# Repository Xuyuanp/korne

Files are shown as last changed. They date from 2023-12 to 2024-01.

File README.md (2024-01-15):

# Korne

| left | right |
| --- | --- |
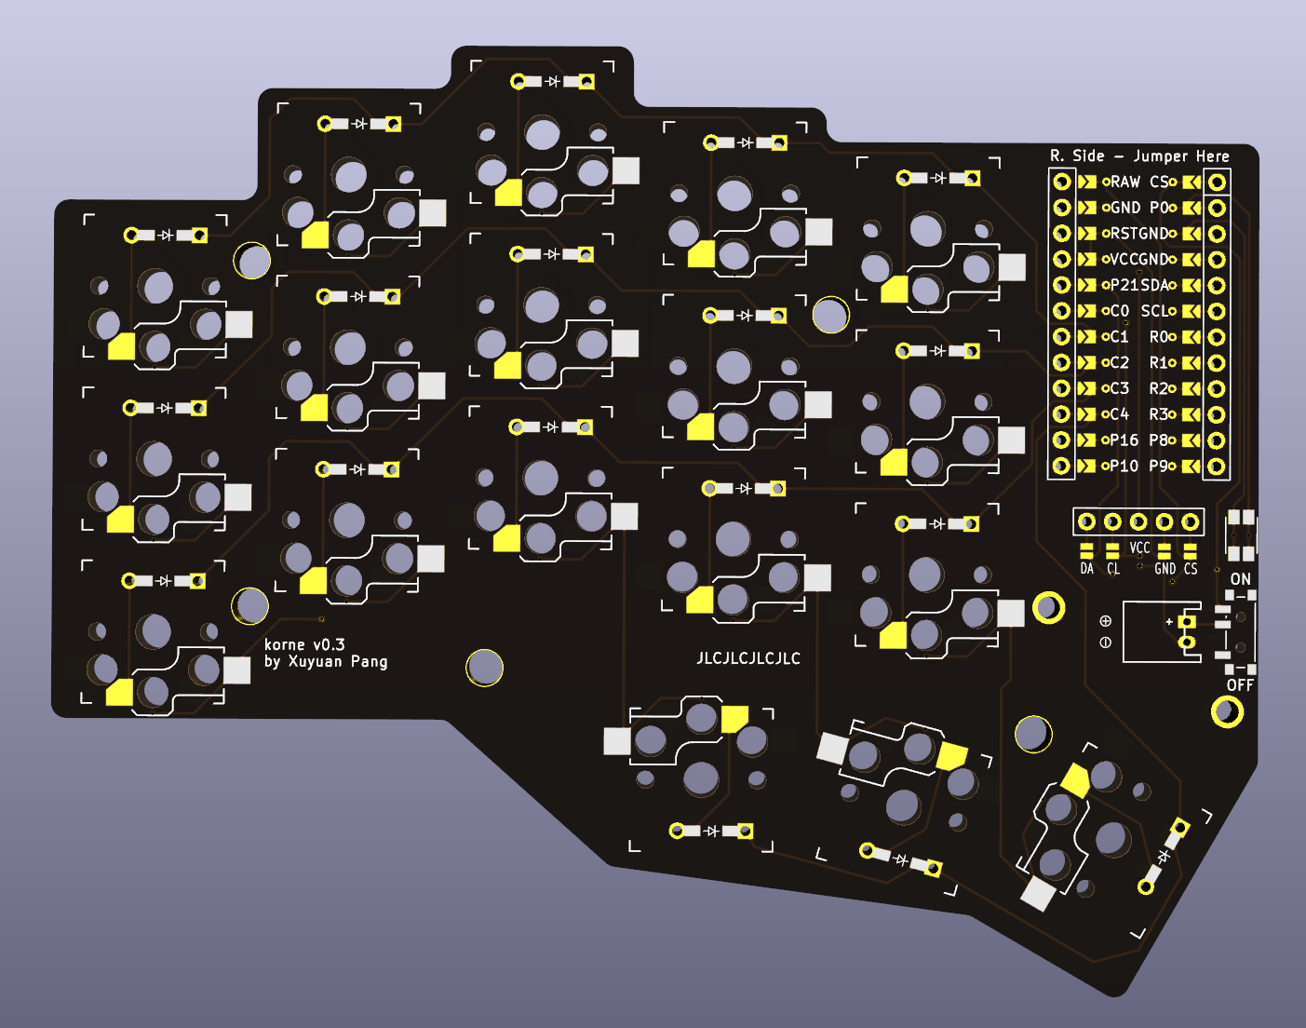
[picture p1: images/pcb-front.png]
front
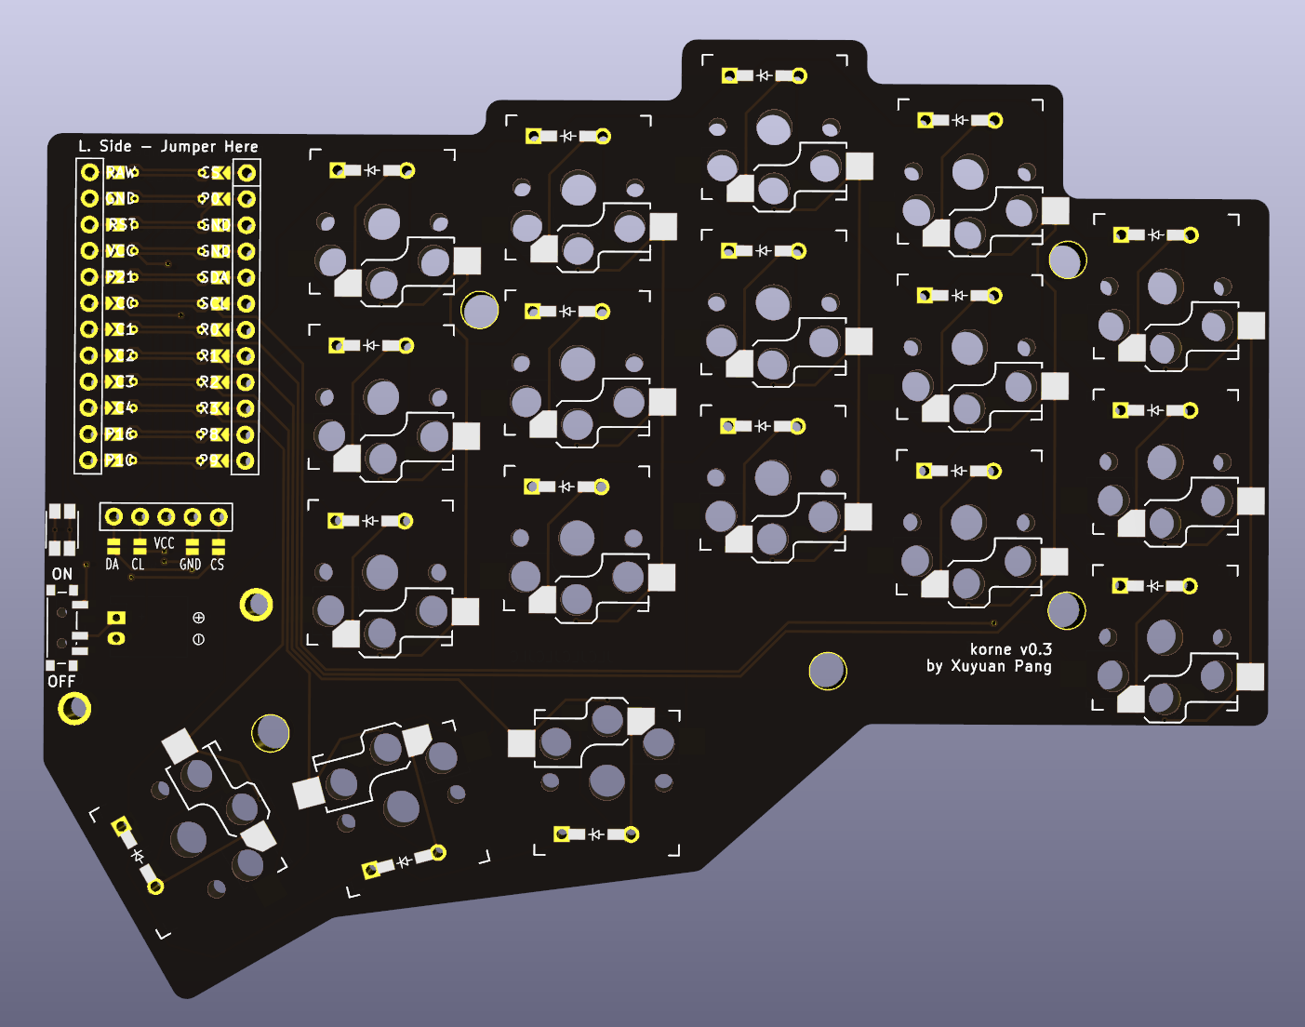
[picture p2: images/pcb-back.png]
back
|  |  |

## Features

- Declarative layout configuration (powered by ergogen)
- Reversible PCB design
- Nice!View support (not tested yet)
- Wireless only
- 3D printed magnetic cases
- Compatible with ZMK firmware of Corne
- The staggered layout fits my hands perfectly

## Credits

- [Ergogen](https://github.com/ergogen/ergogen)
- [ErgoPad](https://pashutk.com/ergopad/)
- [Flatfoot Fox's awesome blog](https://flatfootfox.com/ergogen-introduction/)
- [samoklava](https://github.com/soundmonster/samoklava)
- [infused-kim's footprints
](https://github.com/infused-kim/kb_ergogen_fp)

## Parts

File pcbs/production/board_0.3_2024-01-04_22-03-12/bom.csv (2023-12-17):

Designator | Footprint | Quantity | Value | LCSC Part #
H1, H2, H3, H4, H5, H6, H7 | mounting_hole | 7
JST1 | JST_PH_S2B-PH-K_02x2.00mm_Angled | 1
SW1 | sw_reset_side | 1
SW2 | power_switch | 1

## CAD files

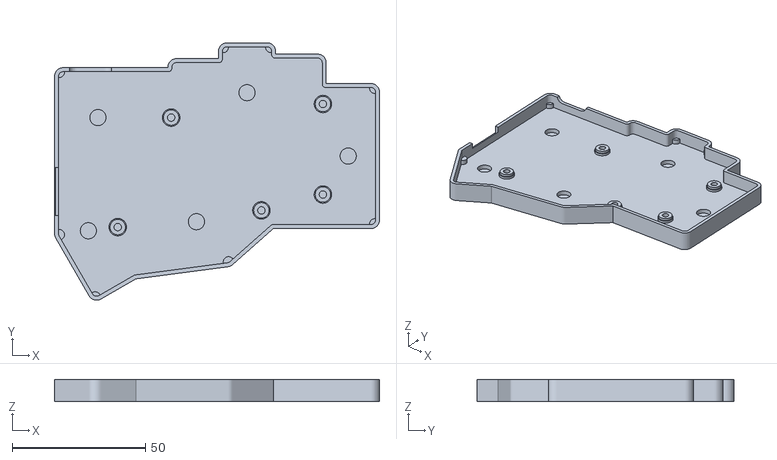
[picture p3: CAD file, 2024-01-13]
cases/bottom-mirrord.stl
122.1 x 96.7 x 8.30

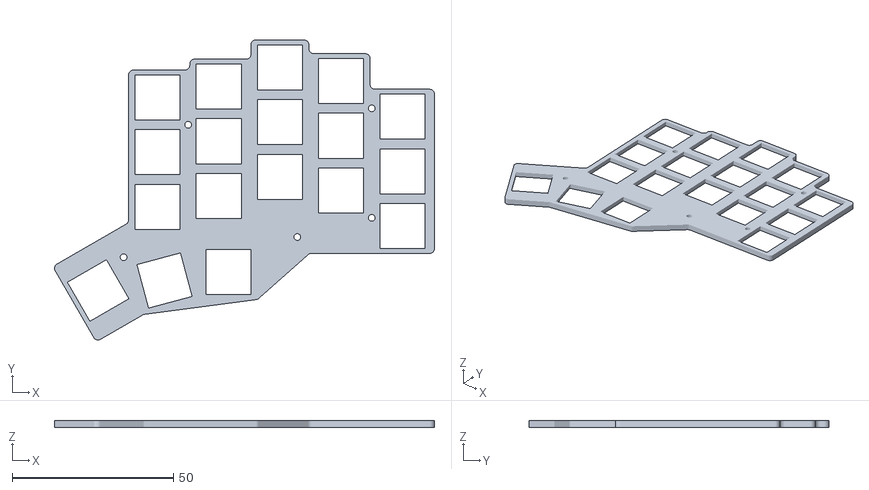
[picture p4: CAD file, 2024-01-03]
cases/top-mirrord.stl
118.0 x 93.2 x 2.20

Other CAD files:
cases/bottom.stl
cases/top.stl

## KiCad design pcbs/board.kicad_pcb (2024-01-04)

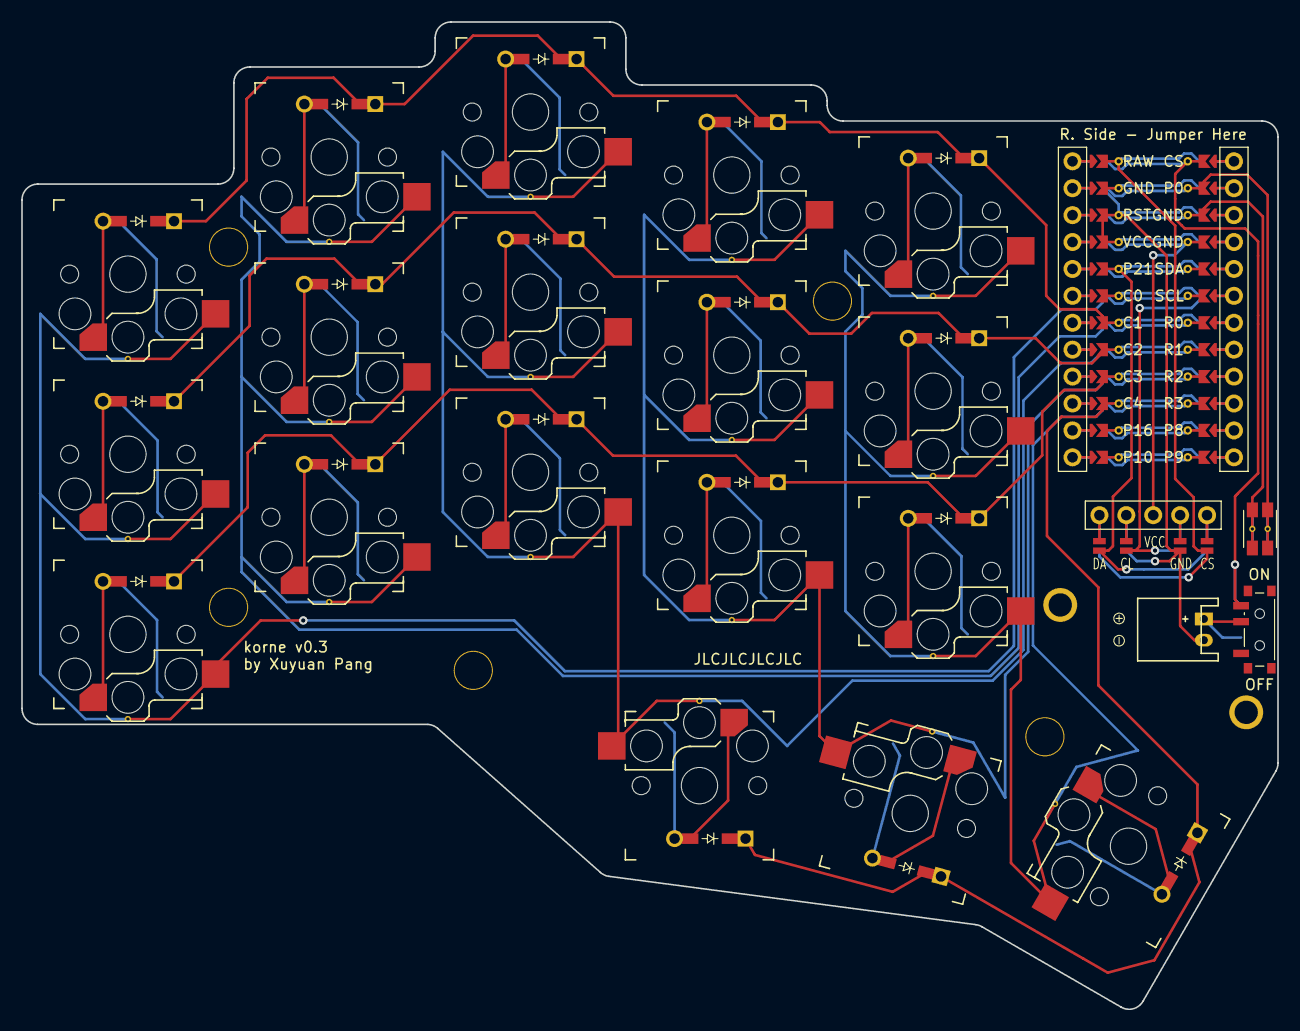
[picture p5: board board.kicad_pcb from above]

Board: 2 copper layers, 118.6 x 93.2 mm, 49 parts (0 on the bottom side), 39 nets.

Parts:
D1, D2, D3, D4, D5, D6, D7, D8, D9, D10, D11, D12, D13, D14, D15, D16, D17, D18: ComboDiode
DISP1: nice!view
H1, H2, H3, H4, H5, H6, H7: mounting_hole
ICON1: icon_bat
JST1: JST_PH_S2B-PH-K_02x2.00mm_Angled
MCU1: nice_nano
S1, S2, S3, S4, S5, S6, S7, S8, S9, S10, S11, S12, S13, S14, S15, S16, S17, S18: PG1350
SW1: sw_reset_side
SW2: power_switch

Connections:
BAT+: JST1.1, SW2.2, SW2.5
CS: DISP1.13, DISP1.23, MCU1.124
DISP1_1: DISP1.1, DISP1.14, DISP1.27
DISP1_2: DISP1.2, DISP1.15, DISP1.26
DISP1_4: DISP1.4, DISP1.16, DISP1.25
DISP1_5: DISP1.5, DISP1.17, DISP1.24
GND: DISP1.12, DISP1.22, JST1.2, MCU1.2, MCU1.121, MCU1.122, SW1.2
MOSI: DISP1.10, DISP1.20, MCU1.120
RAW: MCU1.1, SW2.3, SW2.6
RST: MCU1.3, SW1.1
SCK: DISP1.11, DISP1.21, MCU1.119
VCC: DISP1.3, MCU1.4
col_index: MCU1.9, S10.2, S11.2, S12.2, S16.2
col_inner: MCU1.10, S13.2, S14.2, S15.2, S18.2
col_middle: MCU1.8, S7.2, S8.2, S9.2, S17.2
col_pinky: MCU1.6, S1.2, S2.2, S3.2
col_ring: MCU1.7, S4.2, S5.2, S6.2
far_thumb: D16.2, S18.1
home_thumb: D17.2, S16.1
index_bottom: D10.2, S10.1
index_home: D11.2, S11.1
index_top: D12.2, S12.1
inner_bottom: D13.2, S13.1
inner_home: D14.2, S14.1
inner_top: D15.2, S15.1
middle_bottom: D7.2, S7.1
middle_home: D8.2, S8.1
middle_top: D9.2, S9.1
near_thumb: D18.2, S17.1
pinky_bottom: D1.2, S1.1
pinky_home: D2.2, S2.1
pinky_top: D3.2, S3.1
ring_bottom: D4.2, S4.1
ring_home: D5.2, S5.1
ring_top: D6.2, S6.1
row_bottom: D1.1, D4.1, D7.1, D10.1, D13.1, MCU1.116
row_home: D2.1, D5.1, D8.1, D11.1, D14.1, MCU1.117
row_thumb: D16.1, D17.1, D18.1, MCU1.115
row_top: D3.1, D6.1, D9.1, D12.1, D15.1, MCU1.118

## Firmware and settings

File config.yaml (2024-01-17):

meta:
  version: 0.3.1
  name: korne
  author: XuyuanPang

units:
  kx: cx
  ky: cy

  pd: 2
  px: kx + pd
  py: ky + pd

  thumb_shift: 1.6 ky

  mcu_width: 17.78
  mcu_height: 33

  pcb_height: 1.6
  bottom_height: 2.5
  bottom_wall_thickness: 1.5
  bottom_wall_adjust: 0.25
  usbc_notch_radius: 3
  usbc_notch_width: 10
  support_radius: 2
  switch_height: 2.2
  plate_height: 1.3
  standoff_height: 3 + 0.2
  socket_height: 2
  magnet_slot_radius: 3.05
  magnet_slot_depth: 2
  rubber_radius: 4.05
  rubber_height: 1.4
  m2r: 1.05 # radius of m2 screw
  screw_hole_size: m2r # screw hole size

points:
  key:
    width: kx
    height: ky
    bind: 0
  zones:
    matrix:
      key:
        padding: ky
        spread: u
      columns:
        pinky.key:
          column_net: col_pinky
          bind: [0.5 pd, 0]
        ring.key:
          stagger: 0.65 ky
          column_net: col_ring
          bind: [0, 0.5 pd, 0, 0]
        middle.key:
          stagger: 0.25 ky
          column_net: col_middle
        index.key:
          stagger: -0.35 ky
          column_net: col_index
          bind: [0, 0, 0, 0.5 pd]
        inner.key:
          stagger: -0.2 ky
          column_net: col_inner
          bind: [0, 0, 0, 0.5 pd]
      rows:
        bottom:
          row_net: row_bottom
        home:
          row_net: row_home
        top:
          row_net: row_top
    thumbfan:
      anchor:
        - ref: matrix_inner_bottom
          shift: [0.5 kx, -0.5 ky / 1.732]
          rotate: -30
        - shift: [thumb_shift, 0]
          rotate: 90
        - shift: [-0.75 kx, 0.5 ky]
      key:
        spread: -kx
      columns:
        far.key:
          width: 1.5 kx
          column_net: col_inner
        _bridge_far_home.key:
          spread: -0.25 kx - 0.5 (kx - ky)
          splay: -90
          skip: true
        home.key:
          splay: 15
          spread: -0.5 (kx + ky)
          origin: [0.5 kx, -0.5 ky]
          column_net: col_index
        near.key:
          splay: 15
          origin: [0.5 kx, -0.5 ky]
          column_net: col_middle
      rows:
        thumb.row_net: row_thumb

    _helper_topright:
      anchor:
        - ref: matrix_inner_top
          shift: [0, 0.5 ky]
          affect: "y"
        - ref: thumbfan_far_thumb
          shift: [0.75 kx, -0.5 ky]
          affect: "x"

    # helpers to draw mcu area
    _helper_mcu_topleft:
      anchor:
        - ref: matrix_inner_top
          shift: [0.5 kx, 0.5 ky]
    _helper_mcu_bottomright:
      anchor:
        - ref: thumbfan_far_thumb
          shift: [0.75 kx, -0.5 ky]
          rotate: -90
    _helper_mcu_bottomleft:
      anchor:
        - ref: _helper_mcu_bottomright
          shift: [-thumb_shift, 0]
    _helper_mcu_topright:
      anchor:
        - ref: _helper_mcu_topleft
          affect: "y"
        - ref: _helper_mcu_bottomright
          affect: "x"
    _helper_mcu_topmiddle:
      anchor:
        - aggregate.parts:
          - ref: _helper_mcu_topleft
          - ref: _helper_mcu_topright

    _helper_mcu_cover_holes_low:
      anchor:
        - ref: _helper_mcu_bottomright
          rotate: 60
        - shift: [0, 3 * 2]
    _helper_mcu_cover_holes_high:
      anchor:
        - ref: _helper_mcu_bottomleft
          rotate: -30
        - shift: [0, 1.73205081 * 2]

    _helper_thumbfan_bottom:
      anchor:
        - ref: thumbfan_far_thumb
          shift: [-0.75 kx, -0.5 ky]
    _helper_thumbfan_bottomleft:
      anchor:
        - ref: thumbfan_near_thumb
          shift: [-0.5 kx, -0.5 ky]

    _helper_matrix_topleft:
      anchor:
        - ref: matrix_pinky_top
          shift: [-0.5 px, 0.5 ky]
    _helper_matrix_bottomleft:
      anchor:
        - ref: matrix_pinky_bottom
          shift: [-0.5 px, -0.5 ky]

    _helper_screw_holes_topleft:
      anchor:
        - aggregate.parts:
          - ref: matrix_pinky_top
          - ref: matrix_ring_top
          affect: "x"
        - aggregate.parts:
          - ref: matrix_ring_top
          - ref: matrix_ring_home
          affect: "y"
    _helper_screw_holes_bottomleft:
      anchor:
        - aggregate.parts:
          - ref: matrix_pinky_home
          - ref: matrix_ring_home
          affect: "x"
        - ref: matrix_ring_bottom
          shift: [-0.5 px, -0.5 ky]
          affect: "y"
    _helper_screw_holes_topright:
      anchor:
        - aggregate.parts:
          - ref: matrix_index_top
          - ref: matrix_inner_top
          affect: "x"
        - aggregate.parts:
          - ref: matrix_inner_top
          - ref: matrix_inner_home
          affect: "y"
    _helper_screw_holes_palm:
      anchor:
        - ref: matrix_middle_bottom
          shift: [-0.3 kx, -1.1 ky]
    _helper_screw_holes_thumb:
      anchor:
        - ref: thumbfan_far_thumb
          shift: [5, 3 + 0.5 kx]
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

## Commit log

2023-12-11 improved pcbs
2023-12-11 removed switch solder holes
2023-12-11 adjust diode
2023-12-11 rotate reset button
2023-12-12 relocated footprints
2023-12-13 added mounting_holes added silks reverse nice view's jumper
    [config.yaml]
2023-12-14 added mcu cover mounting holes
2023-12-14 added top case
2023-12-17 updated pcbs and cases
2023-12-17 feat(cases): added magnet slots
2023-12-17 added pcbs and cases
    [board.kicad_pcb, bom.csv, bottom-left.stl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]
2023-12-17 feat(cases): updated bottom case
    [bottom-left.stl, bottom-right.stl, bottom.stl]
2023-12-17 chore: added pcb preview images
2023-12-17 chore: updated pcb images
2023-12-23 feat(pcbs): more compact
2023-12-23 feat(pcbs): customized diode
2023-12-23 feat(pcbs): updated jlc maker
2023-12-23 feat(pcbs): adjust mcu cover screw holes
2023-12-24 feat(cases): added switch notch
2023-12-24 feat(cases): added standoff roots
2023-12-24 feat(cases): added pcb supports
2023-12-24 feat(pcbs,cases): removed vertical padding
2023-12-24 feat(cases): adjust pcb supports
2023-12-24 chore: release v0.2
    [board.kicad_pcb, bottom-left.stl, bottom-right.stl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]
2023-12-30 feat(pcbs): swap net of reset switch
    [config.yaml]
2023-12-30 feat(pcbs): rotate switches
2023-12-30 feat(cases): make mirrord cases
    [bottom-left.stl, bottom-mirrord.stl, bottom-right.stl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]
2024-01-02 feat(cases): improved mountings
2024-01-03 feat(pcbs): added routed v0.3 pcb
    [board.kicad_pcb, bom.csv, bottom-mirrord.stl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]
2024-01-04 feat(pcbs): adjust traces & updated preview images
    [board.kicad_pcb]
2024-01-04 feat(pcbs): added gerbers
    [bom.csv, designators.csv, positions.csv]
2024-01-05 feat(pcbs): updated preview images
2024-01-06 feat(pcbs): updated keycaps size
2024-01-07 feat(cases): adjust bottom screw holes
    [bottom-mirrord.stl, bottom.stl]
2024-01-13 feat(pcbs): updated pcb keycaps preview
2024-01-13 feat(cases): adjust bottom wall
    [bottom-mirrord.stl, bottom.stl]
2024-01-17 feat(pcbs): improved pcb display
